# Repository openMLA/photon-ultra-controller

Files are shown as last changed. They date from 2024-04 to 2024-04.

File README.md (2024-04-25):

# Photon Ultra DLP controller

This repository contains PCB design files and code to control the UV projector found on the [Anycubic Photon Ultra](https://store.anycubic.com/products/photon-ultra). It also serves as a general example of how to send data to and control the [DCLP1438 DMD controller](https://www.ti.com/product/DLPC1438) through the parallel video interface.

The replacement board allows users to generate the signals required for the *DLP controller board* (designed by eViewTek) & DMD that comes with the photon ultra. It does not capture the full functionality of the Anycubic mainboard as it does not control the interface LCD, control the mechanics (stepper motor) or run any resin 3D printer slicer software. It **only** controls the DLP projector with an arbitrary 8-bit 1280x720 image. Exposure time can be set per image. It is also possible to play video on the projector, if that is something you have a use for. [Video has been tested up to 30Hz](https://github.com/openMLA/photon-ultra-controller/issues/1#issuecomment-2057936067), but should work up to 60Hz.

This project might be of interest to you if you **own a photon ultra** and are interested in either

1. Using the photon ultra for PCB fabrication (use the DLP to expose a photoresist)
2. Are looking to use a DMD for other applications but are not ready to build your own controller board.

If you are interested in learning more about the Photon Ultra, you can find more information on [this photon ultra teardown blog post](https://nemoandrea.github.io/blog/Anycubic_DLP_teardown/). More images are available on request.

> If you have a projector using the DLPC1438 that uses an SPI interface (rather than parallel video), then you can check out the [PCB design and implementation for the Elegoo-mars-4 DLP](https://github.com/openMLA/elegoo-mars-4-dlp-controller) projector.

### PCB

The PCB is designed around the standard 40-pin header present on the main Raspberry pi boards. Have a look at the required pins in the schematic to determine how to implement it for other boards.

The PCB readme also contains a breakdown of parts and cost in the BOM. The total PCB + raspberry pi zero 2 cost is around **65 euro** including tax. 

Keep in mind that you would also need to get your hands on the PCB and UV projector found in an Anycubic Photon Ultra. When it was still being sold in stores, that printer went for around **300 euros**. Second-hand options would be attractive, as the projector is unlikely to be significantly worn or covered in layers of sticky resin. Alternatively you can try contacting eViewTek and source the optical engine and driver board directly.

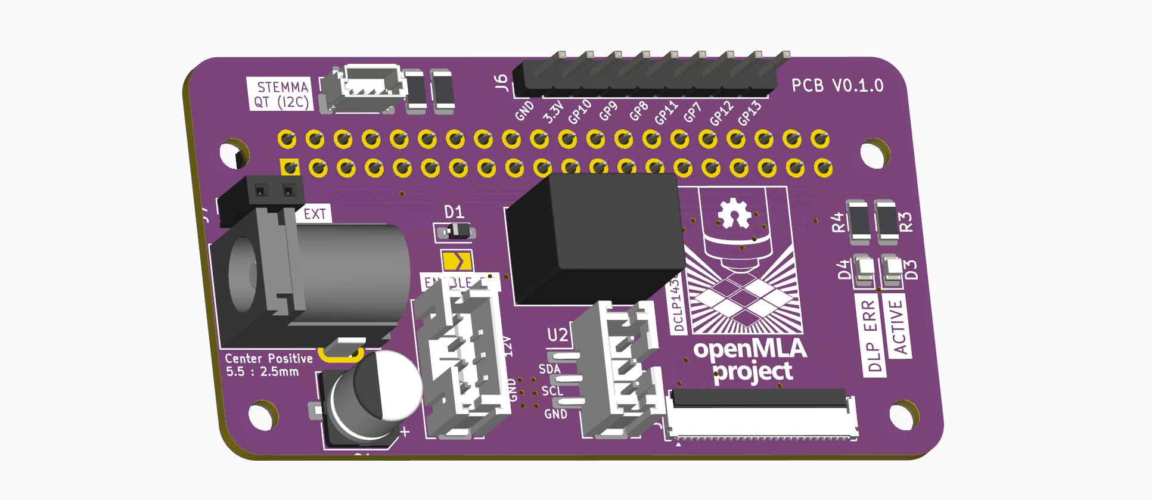
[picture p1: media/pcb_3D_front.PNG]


The PCB has been assembled and verified. Evaluated functionality:

* Powering a Raspberry Pi Zero 2
* Powering the eViewTek board
* software i2c communication (with DLPC1438)
* video display via the parallel interface on the DMD
* Status LED (not currently used in code, but they light up)

Not tested:

* The extra GPIO pins on top (including SPI)
* Stemma QT connection

### Context

This work was developed as part of the [openMLA project](https://github.com/openMLA), where the goal is to build an open hardware lithography system. Eventually an open hardware DLP controller board will be published as part of openMLA, but this represents an intermediate step. 

An earlier attempt at realising the right output format using a rp2040 was partially successful (image display was working), but memory limitations lead to the archiving of that project and the continuation with the current approach, The archived version [is still available](https://github.com/openMLA/photon-ultra-controller-rp2040) for those interested.

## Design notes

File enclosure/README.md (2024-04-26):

# 3D-printable enclosure 📦

To protect the electronics and keep the raspberry pi board in a good position relative to the eViewTek board, you can 3D-print the basic enclosure that is included in this directory. You will also need 7 10mm M2.5 bolts and screws.

Files were designed in FreeCAD.

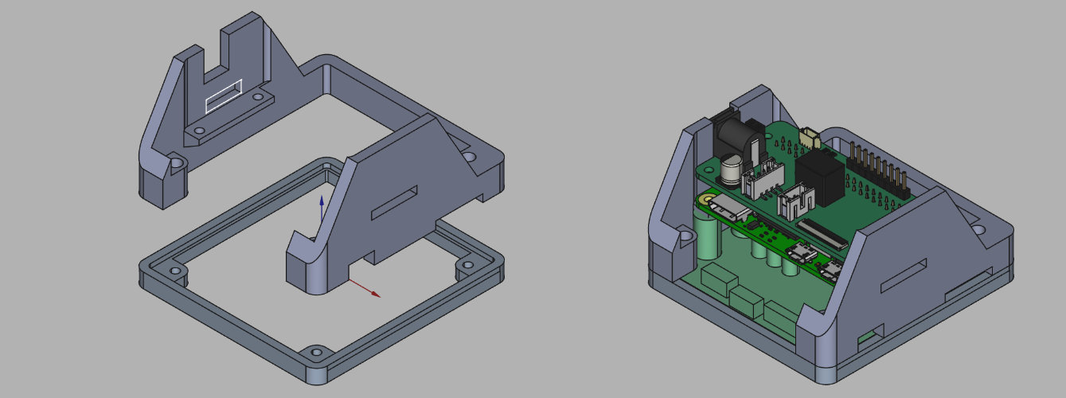
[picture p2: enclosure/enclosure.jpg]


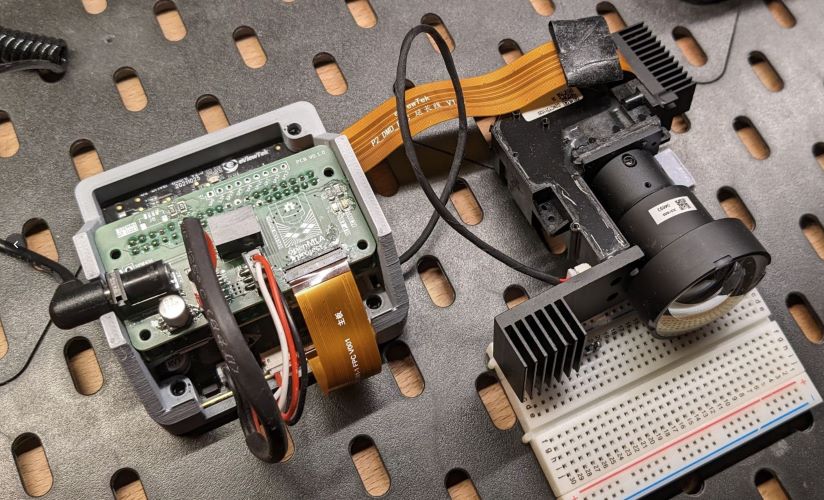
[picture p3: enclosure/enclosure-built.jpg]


### External 3D models

The Model of the raspberry Pi zero 2 was downloaded from [the geekworm wiki](https://wiki.geekworm.com/Raspberry_Pi_Zero_2_W) on 28th of february 2023.

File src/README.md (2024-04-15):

# Controlling the DLPC1438 with I2C and DPI

To control the eViewTek board (which in turn exposes the DCLP1438 parallel and i2c interface to use) we need to be able to output parallel RGB888 video in the right format and to send commands. 

Once you have set up the raspberry pi according to the configuration below, you can run the demo code in `main.py` and start playing around with the projector. 

If you want to play video (and timing is not super critical), you can install `mpv` and play video with `mpv <video.mp4>` (depending on orientation you may want to add `-vf=vflip`). Note that you will have to switch the projector into exposure mode (`Mode.EXTERNALPRINT`), otherwise you will not see anything. Any other means of playing video that modifies the framebuffer at `/dev/fb0` should also work.

### Configuring Raspberry pi OS Lite

>  Everything is tested on a Raspberry Pi Zero 2 running Raspbian GNU/Linux 12 (bookworm) (Lite).

To start, we need to make some changes to `/boot/config.txt`.

We need to disable the hardware I2C and SPI (for now at least). Make sure the `dtparams` for i2c, i2s, spi are all commented as below:

```shell
#Uncomment some or all of these to enable the optional hardware interfaces
#dtparam=i2c_arm=on
#dtparam=i2s=on
#dtparam=spi=on
```

Adding DPI: add the following lines: (note that in theory some of the back and front porches could be reduced according to datasheet; untested)

```
dtoverlay=vc4-kms-v3d
dtoverlay=vc4-kms-dpi-generic,hactive=1280,hfp=32,hsync=12,hbp=32
dtparam=vactive=720,vfp=6,vsync=5,vbp=6
dtparam=clock-frequency=32000000,rgb888,pixclk-invert
```

Add software I2C by adding the following lines:

```shell
# get software-defined i2c pin
dtoverlay=i2c-gpio,i2c_gpio_sda=17,i2c_gpio_scl=18,bus=8
```

If we were to leave the config.txt as above, we would lose all our GPIO, but we are not going to use the Green and Blue pixeldata pins anyway, so we would like to get those back for I2C, and other stuff. (i.e. switch them back out from their DPI `ALT` mode )

> [!NOTE]
> The method below works, but I would prefer to switch the pins out of ALT mode earlier on in the boot process. If you know how to do that, make an issue or pull request!

We can achieve this by putting the following in `/etc/rc.local`. Note that is must come before the `exit 0` line. 

```
raspi-gpio set 4-19 ip
```

Then we need to fix one final issue. If we start everything now, we notice that our framebuffer is running in RGB565 mode. Not sure why, but it is not what we want and doesn't match our DPI configuration. Luckily the fix is straightforward. We add the following to `/boot/cmdline.txt`:

```
`video=DPI-1:-32`
```
Note that the above that your DPI interface is called `DPI-1`. You can check this with `kmsprint`. It should list mode [`XR24`](https://www.linuxtv.org/downloads/v4l-dvb-apis-new/userspace-api/v4l/pixfmt-rgb.html). 

#### Checking results

Now (after rebooting) you should get something akin to the following if you run `fbset -fb /dev/fb0`

```shell
mode "1280x720"
    geometry 1280 720 1280 720 32
    timings 0 0 0 0 0 0 0
    accel true
    rgba 8/16,8/8,8/0,0/0
endmode
```

And something similar to the output below when you run `kmsprint`:

```shell
Connector 0 (32) HDMI-A-1 (disconnected)
  Encoder 0 (31) TMDS
Connector 1 (42) DPI-1 (connected)
  Encoder 1 (41) DPI
    Crtc 1 (71) 1280x720@32.02 32.000 1280/32/12/32/+ 720/6/5/6/+ 32 (32.02) P|D
      Plane 1 (61) fb-id: 294 (crtcs: 1) 0,0 1280x720 -> 0,0 1280x720 (XR24 AR24 AB24 XB24 RG16 BG16 AR15 XR15 RG24 BG24 YU16 YV16 YU24 YV24 YU12 YV12 NV12 NV21 NV16 NV61 RGB8 BGR8 XR12 AR12 XB12 AB12 BX12 BA12 RX12 RA12)
        FB 294 1280x720 XR24
```

You can also check the state of the GPIO pins with ``raspi-gpio get``. It should list something like: 

```
BANK0 (GPIO 0 to 27):
GPIO 0: level=0 alt=2 func=PCLK
GPIO 1: level=1 alt=2 func=DE
GPIO 2: level=0 alt=2 func=LCD_VSYNC
GPIO 3: level=0 alt=2 func=LCD_HSYNC
GPIO 4: level=1 func=INPUT
GPIO 5: level=1 func=INPUT
GPIO 6: level=0 func=INPUT
GPIO 7: level=1 func=INPUT
GPIO 8: level=1 func=INPUT
GPIO 9: level=0 func=INPUT
GPIO 10: level=0 func=INPUT
GPIO 11: level=0 func=INPUT
GPIO 12: level=0 func=INPUT
GPIO 13: level=0 func=INPUT
GPIO 14: level=0 func=INPUT
GPIO 15: level=1 func=INPUT
GPIO 16: level=0 func=INPUT
GPIO 17: level=1 func=INPUT
GPIO 18: level=1 func=INPUT
GPIO 19: level=0 func=INPUT
GPIO 20: level=0 alt=2 func=DPI_D16
GPIO 21: level=0 alt=2 func=DPI_D17
GPIO 22: level=0 alt=2 func=DPI_D18
GPIO 23: level=0 alt=2 func=DPI_D19
GPIO 24: level=0 alt=2 func=DPI_D20
GPIO 25: level=0 alt=2 func=DPI_D21
GPIO 26: level=0 alt=2 func=DPI_D22
GPIO 27: level=0 alt=2 func=DPI_D23
...
```

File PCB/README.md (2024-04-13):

### PCB design

The design is tested with a raspberry pi zero 2, but in principle any Raspberry pi will work. The hardware pins should all be shared, but some changes in raspberry Pi OS may break stuff for newer boards. 

See [the schematic](micromirror-board-controller.pdf) for more info.



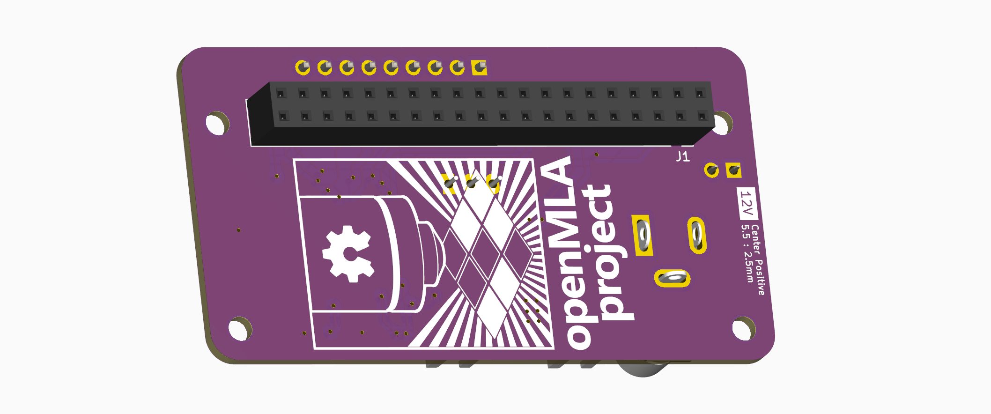
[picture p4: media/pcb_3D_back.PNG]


### Assembly

Most components are SMD, and the mouser links can be found in the basic [BOM](BOM.csv). In addition to the components of the BOM, you will also need some small wires to connect the USB data lines.

That 51-pin connector is a real pain to solder. For me going with a lower melting point solder and proper board heating made it manageable, but it's not the most enjoyable experience.

### BOM

The prices below include Dutch VAT tax (21%). 

| Description | Supplier | Supplier Part Number | Amount | Total Cost | Comment |
| --- | --- | --- | --- | --- | --- |
| PCB manufacturing | Aisler | | 3 | 16.16 | MOC 3pcs |
| Raspberry Pi Zero 2 | Mouser | 358-SC0510 | 1 | 16.9 | |
| Micro SD Card (32GB) | Kiwi Electronics | TS32GUSDU1 | 1 | 10 | Whatever kind you want would work |
| Raspberry pi header | Kiwi Electronics | KW-2639 | 1 | 2 | or any basic, cheaper header |
| Raspberry pi header female | Kiwi Electronics | KW-1650 | 1 | 1.5 | |
| JST SH 4-pin | Mouser | 474-PRT-16766 | 1 | 0.67 | Optional, allows i2c through  stemmaQT/QWIIC |
| Cui DC-DC converter | Mouser | 490-P78E05-1000 | 1 | 3.45 | |
| Barreljack | Mouser | 490-PJ-002B | 1 | 0.79 | |
| Schottky Diode | Mouser | 771-PMEG1020EJ-T/R | 1 | 0.29 | |
| 100uF capacitor | Mouser | 667-EEE-FN1E101UP | 1 | 0.57 | |
| 4.7k Ohm pullup resistor | Mouser | 667-ERA-8AEB472V | 2 | 0.87 | |
| 330 Ohm resistor | Mouser | 667-ERA-8AEB331V | 2 | 0.75 | |
| Green LED | Mouser | 710-150080VS75000 | 1 | 0.22 | |
| Red LED | Mouser | 710-150080RS75000 | 1 | 0.22 | |
| 51-pin FPC connector | Mouser | 798-FH35C51S03SHW50  | 1 | 3.52 | not fun to solder |
| 3 -pin JST PH connector (10pack) | Mouser | 485-4389 | 1 | 3.95 | Probably best to find the single-unit part |
| 4-pin JST PH connector (10pack)  | Mouser | 485-4390 | 1 | 3.95 | Probably best to find the single-unit part |
| | | | | | |
| Total | | | | 65.77 | |

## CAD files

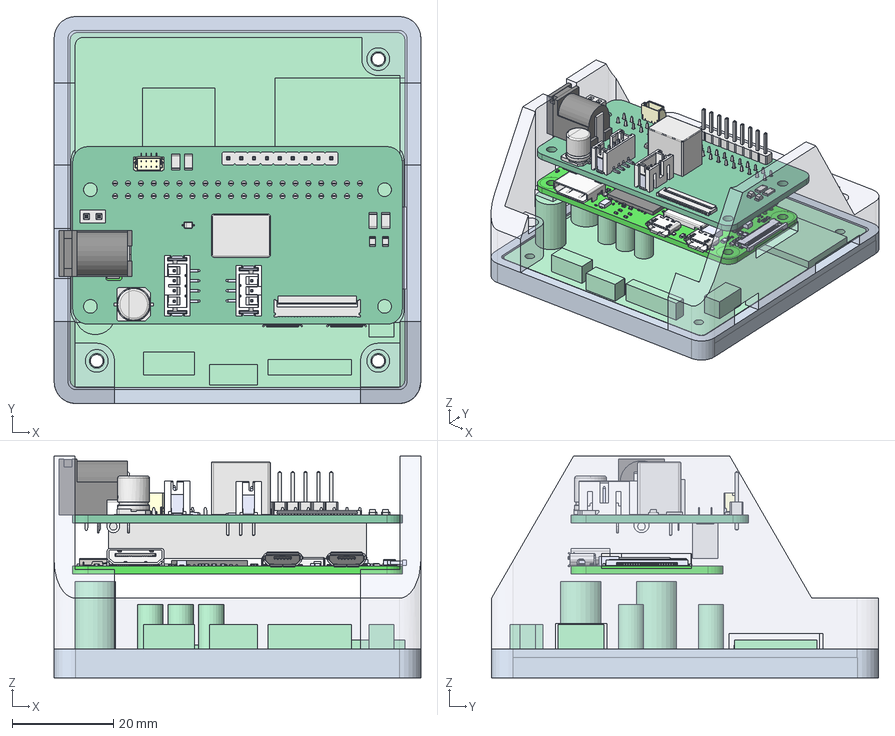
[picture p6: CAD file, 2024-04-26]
enclosure/enclosure.FCStd
72.3 x 76.3 x 43.7 mm
PCB, Raspberry Pi Zero 2 W
RP3A0-AU 2105 201221C, Raspberry Pi Zero 2 W
MicroUSB Port, Raspberry Pi Zero 2 W
MicroUSB Port, Raspberry Pi Zero 2 W001
MicroUSB Port, Raspberry Pi Zero 2 W002
MicroUSB Port, Raspberry Pi Zero 2 W003
MicroUSB Port, Raspberry Pi Zero 2 W004
MicroUSB Port, Raspberry Pi Zero 2 W005
MicroUSB Port, Raspberry Pi Zero 2 W006
SD Card Slot, Raspberry Pi Zero 2 W
SD Card Slot, Raspberry Pi Zero 2 W001
SD Card Slot, Raspberry Pi Zero 2 W002
SD Card Slot, Raspberry Pi Zero 2 W003
SD Card Slot, Raspberry Pi Zero 2 W004
SD Card Slot, Raspberry Pi Zero 2 W005
SD Card Slot, Raspberry Pi Zero 2 W006
SD Card Slot, Raspberry Pi Zero 2 W007
SD Card Slot, Raspberry Pi Zero 2 W008
SD Card Slot, Raspberry Pi Zero 2 W009
Wireless Module Cover, Raspberry Pi Zero 2 W
Crystal Resonator, Raspberry Pi Zero 2 W
LED, Raspberry Pi Zero 2 W
Diode, Schottky, Raspberry Pi Zero 2 W
54548-2271, 22 Pin FPC Connector, Raspberry Pi Zero 2 W
Mini HDMI Receptacle Port, Raspberry Pi Zero 2 W
PAM2306AYPKE, Switching Voltage Regulators Dual PWM Step-Down 40uA 1A 1.5MHz, Raspberry Pi Zero 2 W
RT9081A-1BGQZA, Fixed LDO Voltage Regulator, 0.8V-5.5Vin, 140mV drop, 1.25Vout, 0.5Aout, Raspberry Pi Zero 2 W_default
RT8088AWSC, IC Reg Buck Prog 3A Sync 15WLCSP, Raspberry Pi Zero 2 W_default
SMD Inductor, Configurable, Raspberry Pi Zero 2 W_L1
SMD Inductor, Configurable, Raspberry Pi Zero 2 W_L2
SMD Capacitor, Configurable, Raspberry Pi Zero 2 W_C1
SMD Capacitor, Configurable, Raspberry Pi Zero 2 W_C002
SMD Capacitor, Configurable, Raspberry Pi Zero 2 W_C003
MicroUSB Port, Raspberry Pi Zero 2 W008
MicroUSB Port, Raspberry Pi Zero 2 W009
MicroUSB Port, Raspberry Pi Zero 2 W010
MicroUSB Port, Raspberry Pi Zero 2 W011
MicroUSB Port, Raspberry Pi Zero 2 W012
MicroUSB Port, Raspberry Pi Zero 2 W013
MicroUSB Port, Raspberry Pi Zero 2 W014
SMD Capacitor, Configurable, Raspberry Pi Zero 2 W_C3
SMD Capacitor, Configurable, Raspberry Pi Zero 2 W_C005
SMD Capacitor, Configurable, Raspberry Pi Zero 2 W_C006
SMD Capacitor, Configurable, Raspberry Pi Zero 2 W_C008
SMD Capacitor, Configurable, Raspberry Pi Zero 2 W_C009
SMD Capacitor, Configurable, Raspberry Pi Zero 2 W_C010
SMD Capacitor, Configurable, Raspberry Pi Zero 2 W_C012
SMD Capacitor, Configurable, Raspberry Pi Zero 2 W_C013
SMD Capacitor, Configurable, Raspberry Pi Zero 2 W_C014
SMD Capacitor, Configurable, Raspberry Pi Zero 2 W_C016
SMD Capacitor, Configurable, Raspberry Pi Zero 2 W_C017
SMD Capacitor, Configurable, Raspberry Pi Zero 2 W_C018
SMD Capacitor, Configurable, Raspberry Pi Zero 2 W_C020
SMD Capacitor, Configurable, Raspberry Pi Zero 2 W_C021
SMD Capacitor, Configurable, Raspberry Pi Zero 2 W_C022
SMD Capacitor, Configurable, Raspberry Pi Zero 2 W_C024
SMD Capacitor, Configurable, Raspberry Pi Zero 2 W_C025
SMD Capacitor, Configurable, Raspberry Pi Zero 2 W_C026
SMD Capacitor, Configurable, Raspberry Pi Zero 2 W_C028
SMD Capacitor, Configurable, Raspberry Pi Zero 2 W_C029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

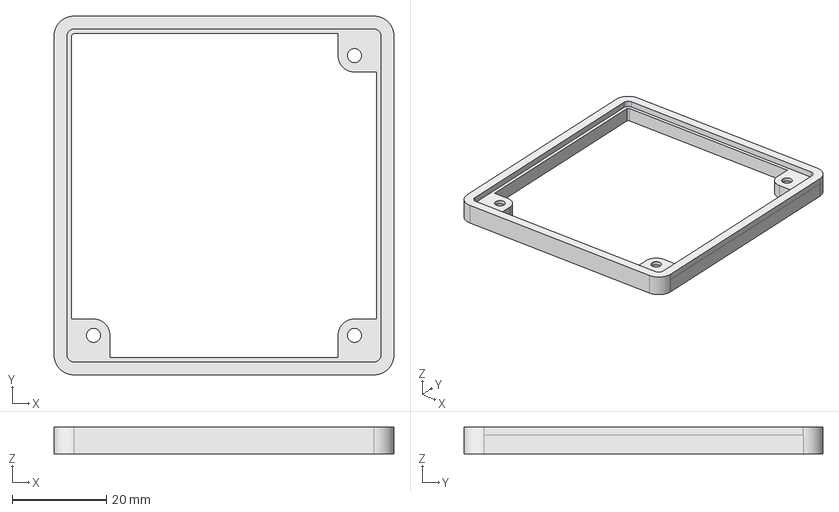
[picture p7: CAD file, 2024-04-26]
enclosure/step/enclosure-bottom.step
72.3 x 76.3 x 5.70 mm

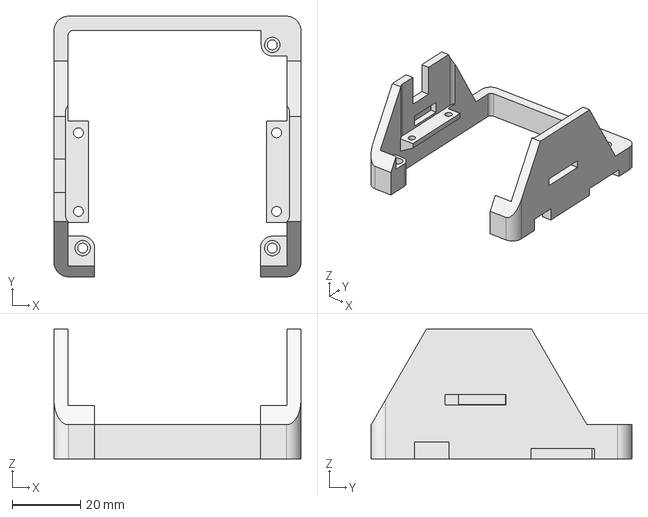
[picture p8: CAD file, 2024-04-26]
enclosure/step/enclosure-top.step
72.3 x 76.3 x 38.0 mm

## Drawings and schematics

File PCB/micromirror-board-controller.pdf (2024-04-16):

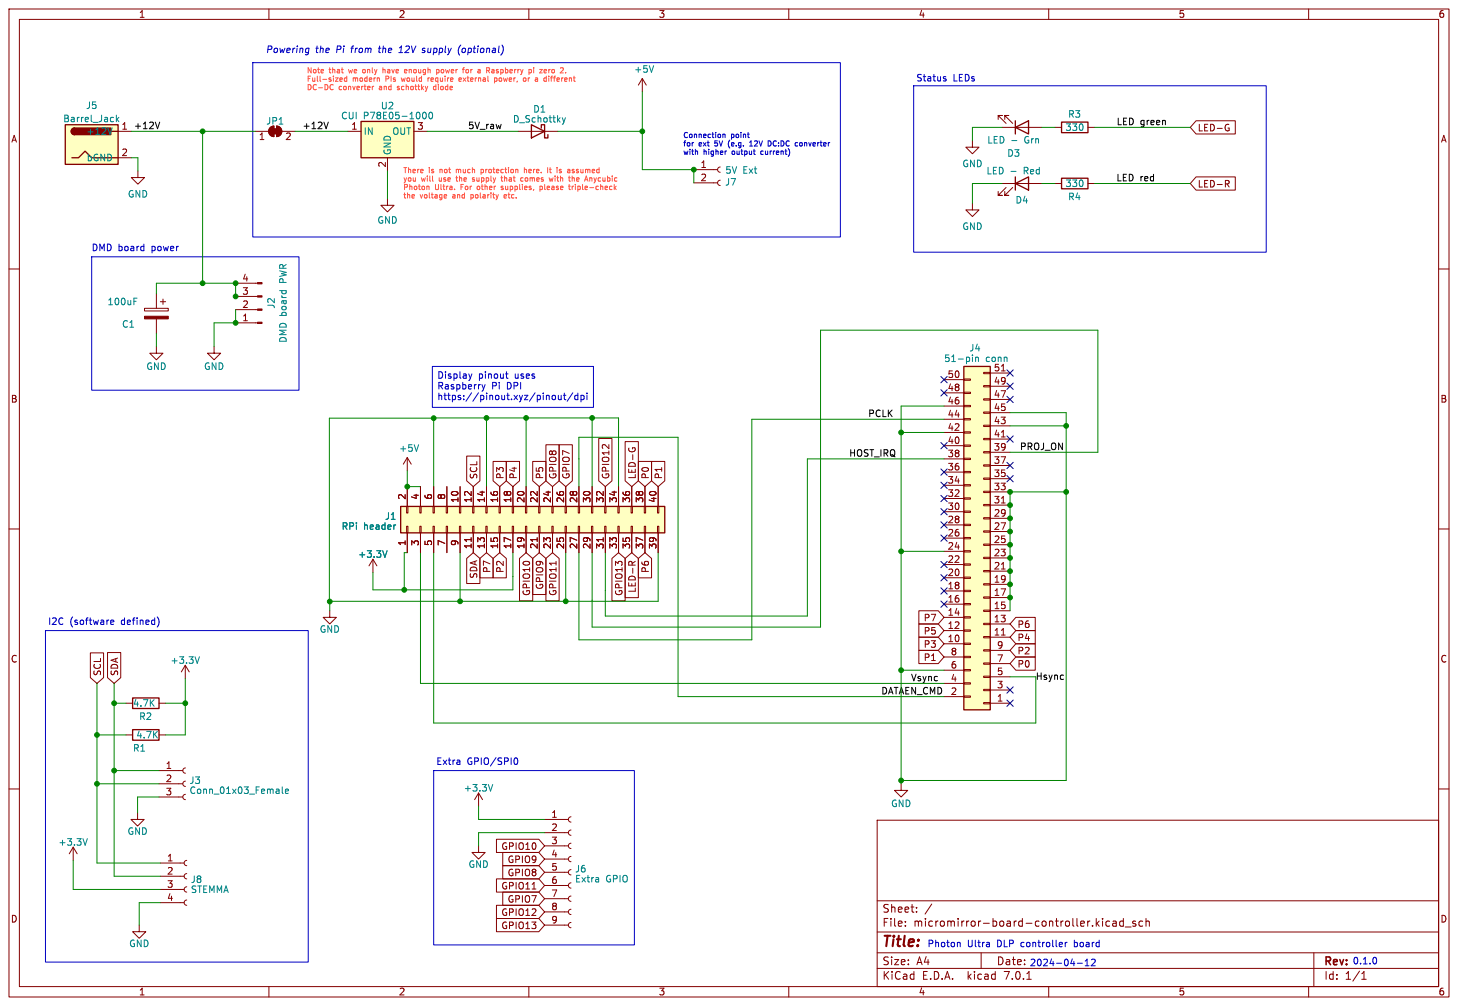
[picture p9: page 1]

for ext 5V (e.g. 12V DC:DC converter with higher output current)

Id: 1/1 Title: File: micromirror-board-controller.kicad_sch Sheet: /

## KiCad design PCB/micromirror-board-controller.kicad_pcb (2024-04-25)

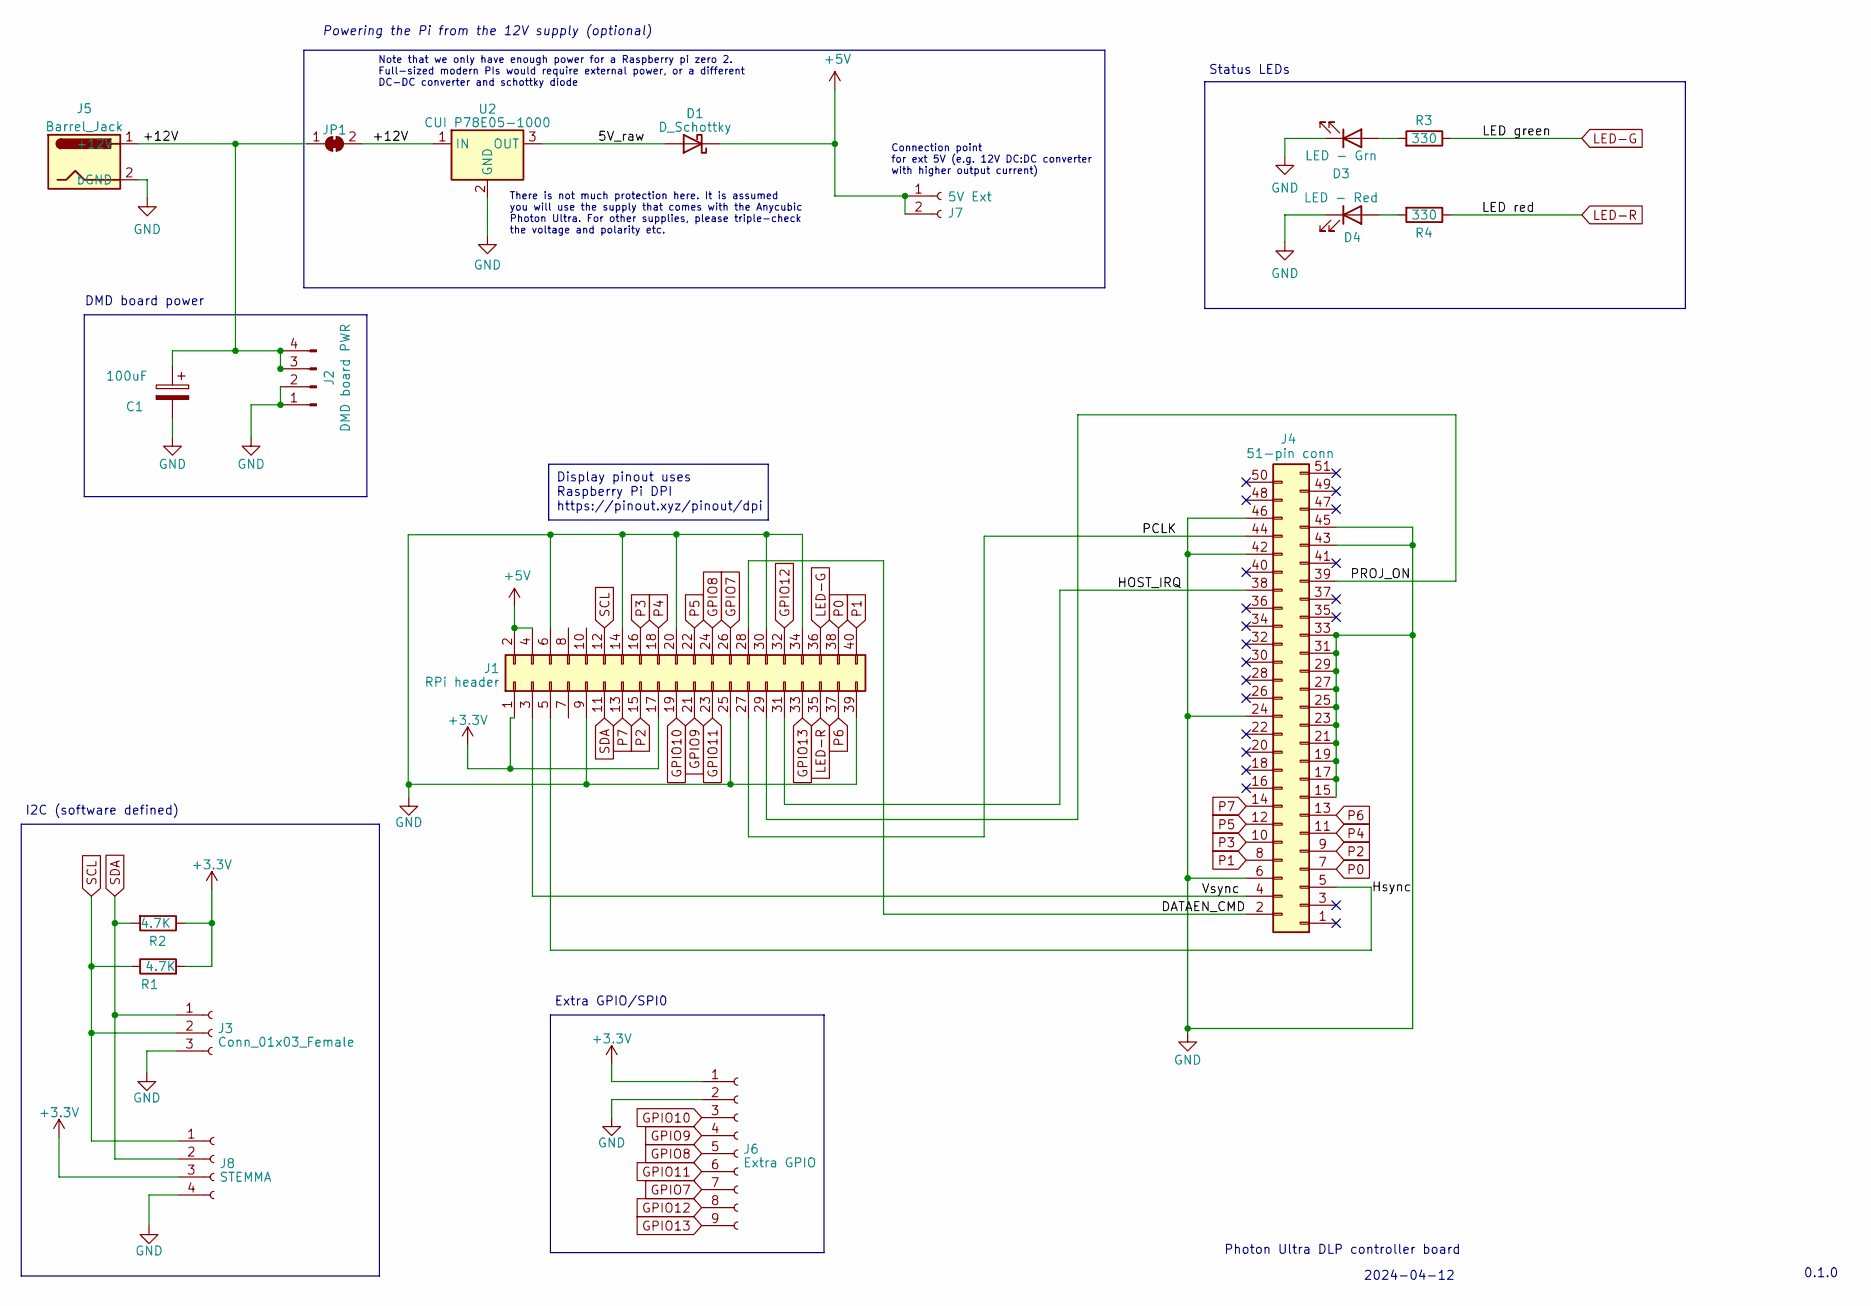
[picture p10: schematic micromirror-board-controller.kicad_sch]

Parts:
C1: 100uF; CP_Elec_6.3x7.7
D1: D_Schottky; D_SOD-323_HandSoldering; Mouser 771-PMEG1020EJ-T/R
D3: LED - Grn; LED_0805_2012Metric; Mouser 710-150080VS75000
D4: LED - Red; LED_0805_2012Metric; Mouser 710-150080RS75000
J1: RPi header; PinSocket_2x20_P2.54mm_Vertical
J2: DMD board PWR; JST_PH_B4B-PH-SM4-TB_1x04-1MP_P2.00mm_Vertical; Mouser 485-4390
J3: Conn_01x03_Female; JST_PH_B3B-PH-SM4-TB_1x03-1MP_P2.00mm_Vertical; Mouser 485-4389
J4: 51-pin conn; Molex_502250-5191_2Rows-51Pins-1MP_P0.60mm_Horizontal; Mouser-id 798-FH35C51S03SHW50
J5: Barrel_Jack; BarrelJack_GCT_DCJ200-10-A_Horizontal
J6: Extra GPIO; PinHeader_1x09_P2.54mm_Vertical
J7: 5V Ext; PinSocket_1x02_P2.54mm_Vertical
J8: STEMMA; JST_SH_BM04B-SRSS-TB_1x04-1MP_P1.00mm_Vertical; Mouser 474-PRT-16766
JP1: SolderJumper_2_Bridged; SolderJumper-2_P1.3mm_Open_TrianglePad1.0x1.5mm
R1: 4.7K; R_1206_3216Metric
R2: 4.7K; R_1206_3216Metric; Mouser 667-ERA-8AEB472V
R3, R4: 330; R_1206_3216Metric
U2: CUI P78E05-1000; Converter_DCDC_RECOM_R-78E-0.5_THT; Mouser 490-P78E05-1000

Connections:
+3.3V: J1.1, J1.17, J6.1, J8.3, R1.2, R2.1
+5V: D1.1 (K), J1.2, J1.4, J7.1, J7.2
/5V_raw: D1.2 (A), U2.3 (OUT)
/+12V: C1.1, J2.3, J2.4, J5.1 (+12V), JP1.1 (A), JP1.2 (B), U2.1 (IN)
/DATAEN_CMD: J1.28, J4.2 (DATAEN)
/HOST_IRQ: J1.31, J4.38 (HOST_IRQ)
/Hsync: J1.5, J4.5 (Hsync)
/PCLK: J1.27, J4.44 (PCLK)
/PROJ_ON: J1.29, J4.39 (GPIO_9)
/Vsync: J1.3, J4.4 (Vsync)
GND: C1.2, D3.1 (K), D4.1 (K), J1.6, J1.9, J1.14, J1.20, J1.25, J1.30, J1.34, J1.39, J2.1, J2.2, J3.3 (SDA), J4.6 (GND), J4.15 (GND), J4.17, J4.19, J4.21, J4.23, J4.24, J4.25, J4.27, J4.29, J4.31, J4.33, J4.42 (GND), J4.43 (GND), J4.45 (GND), J4.46 (GND), J5.2 (bGND), J6.2, J8.4, U2.2 (GND)
GPIO7: J1.26, J6.7
GPIO8: J1.24, J6.5
GPIO9: J1.21, J6.4
GPIO10: J1.19, J6.3
GPIO11: J1.23, J6.6
GPIO12: J1.32, J6.8
GPIO13: J1.33, J6.9
LED-G: J1.36, R3.1
LED-R: J1.35, R4.1
unnamed: D3.2 (A), R3.2
unnamed: D4.2 (A), R4.2
P0: J1.38, J4.7 (P1)
P1: J1.40, J4.8 (P0)
P2: J1.15, J4.9 (P3)
P3: J1.16, J4.10 (P2)
P4: J1.18, J4.11 (P5)
P5: J1.22, J4.12 (P4)
P6: J1.37, J4.13 (P7)
P7: J1.13, J4.14 (P6)
SCL: J1.12, J3.2 (SCL), J8.1, R1.1
SDA: J1.11, J3.1 (dGND), J8.2, R2.2

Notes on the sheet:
Display pinout uses Raspberry Pi DPI https://pinout.xyz/pinout/dpi
Extra GPIO/SPI0
There is not much protection here. It is assumed you will use the supply that comes with the Anycubic Photon Ultra. For other supplies, please triple-check the voltage and polarity etc.
Connection point for ext 5V (e.g. 12V DC:DC converter with higher output current)
Powering the Pi from the 12V supply (optional)
Status LEDs
Note that we only have enough power for a Raspberry pi zero 2. Full-sized modern PIs would require external power, or a different DC-DC converter and schottky diode
DMD board power
I2C (software defined)
Photon Ultra DLP controller board
2024-04-12
0.1.0

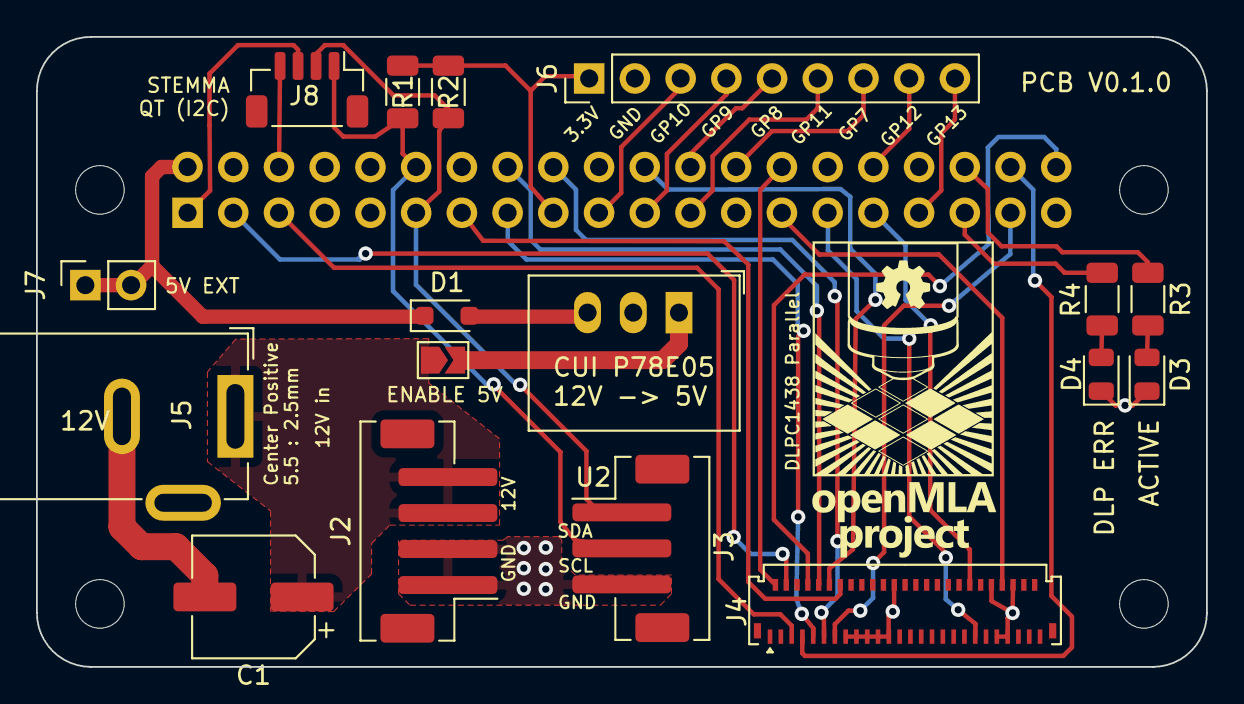
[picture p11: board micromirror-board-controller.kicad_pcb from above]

Board: 2 copper layers, 65.0 x 35.0 mm, 22 parts (1 on the bottom side), 32 nets.

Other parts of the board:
MH1, MH2, MH3, MH4: MountingHole_2.7mm_M2.5

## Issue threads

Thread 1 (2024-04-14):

Maximum Framerate

beniroquai, 2024-04-14:
Hey @NemoAndrea, great stuff - as always! :)
May I ask you what would be the maximum framerate you could achieve with this device? I remember you mentioned 2fps for some DMD+Raspi combination, but this may be different since you use a different controlling interface?
Thanks!:)

NemoAndrea, 2024-04-14:
With the parallel interface and leaving the DMD to keep exposing (no dark frames), it seems to be handling video playback at 30Hz okay, but I need to do more thorough testing to see if it can actually display all 30 frames. But it looks like video alright.

In theory cranking it to 60Hz should be possible; will give it a shot when I find some time. (need to find something to record images with reliably etc)

beniroquai, 2024-04-15:
That's awesome! I want one ;D
The DLP modules from anycubic are available as a spare part or do you need to go through the full teardown everytime you need one? ;-)

NemoAndrea, 2024-04-15:
eViewTek will (when I asked in january 2024) sell you the optical engine and diver board separately. I was able to get a quote, which was pretty reasonable. I don't know how much stock they have and if they are keeping it in production.

NemoAndrea, 2024-04-15:
Now in 8-bit :) This should still be ~30Hz

https://github.com/openMLA/photon-ultra-controller/assets/8851596/1073c735-3f78-4d0c-9457-03acd0ee8ca6

beniroquai, 2024-04-16:
Wow! That is super cool! It's a natural idea to think of using this DMD as the pattern generator for our SIM systems. I'm looking for old Elegoos on Ebay. Maybe I find one that is not that expensive. Impressive! Thanks for sharing. 30 fps is already pretty awesome. One could use the raspi as the trigger device, too, right?

CC: @ranranking

NemoAndrea, 2024-04-16:
Yep, the expose can be enabled over i2c. There is then the option to (1) expose for a certain amount of frames, controlled/intrepreted by the DLPC1438, to (2) to expose until the "STOP EXPOSURE" i2c command is sent.

So you could leave it in mode (2) and use the framebuffer to switch between expose/stop light/change pattern/light on/expose/ stop light/change pattern/  or (1) and i2c-start->expose->i2c-stop->change pattern->i2c-start->expose. Depends a bit on how problematic the "changing DMD mirror positions" is as it transitions between frames I guess.

beniroquai, 2024-04-16:
Amazing! Thanks a lot for all the information! I found one on ebay. Potentially broken. Awesome! ^^

Closed 2024-04-15.

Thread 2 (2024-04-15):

grayscale pins swapped

NemoAndrea, 2024-04-15:
Noticed that the grayscale pins are swapped in board revision 0.1.0. Need to correct in PCB design. Happy I caught that before ordering and assembling.

(pins 0<->1, pins 2<->3, etc).

Closed 2024-04-16.

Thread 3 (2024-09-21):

Would this be directly compatible with a Pi 3b or a Pi4?

X3msnake, 2024-09-21:
Managed to aquire one Ultra as is returns on official anycubic ebay.

I wanted to use @sn4k3 [Klipper-MSLA](https://github.com/sn4k3/klipper-msla ) branch to controll a custom printer with zoom and focus capacity on the DLP side.

Would the current shield work directly on a Pi3B, Pi4 or would i need to make changes to the schematic?

Btw do you have a paypal tip button anywhere?
Thanks in advance

sn4k3, 2024-09-21:
I have an additional question, I saw you using software I2C, any special reason to go software instead of hardware I2C?

NemoAndrea, 2024-10-20:
I think it should work on those Pis, but the thing to check would be if there are any special changes with the respect to the Display Parallel Interface (DPI). Other than that i think the hardware should be fine.

Please do report back if it gives you trouble; we can try to see what must be changed software wise or hardware.

NemoAndrea, 2024-10-20:
> I have an additional question, I saw you using software I2C, any special reason to go software instead of hardware I2C?

The DPI occupies the hardware i2c pins and they cannot be remapped unfortunately. So software it is 😃

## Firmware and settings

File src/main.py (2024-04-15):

import RPi.GPIO as GPIO
import time
import smbus  # I2C
from PIL import Image

from UV_projector.controller import DLPC1438, Mode

GPIO.setmode(GPIO.BCM)

HOST_IRQ = 6  # GPIO pin for HOST_IRQ
PROJ_ON = 5  # GPIO pin for PROJ_ON

i2c = smbus.SMBus(8)  # we configured our software i2c to be on bus 8

### Controlling DMD ################################################################################

# Initialise the DLPC1438
DMD = DLPC1438(i2c, PROJ_ON, HOST_IRQ)
# Configure it (NOTE: Mode.STANDBY can clear these settings, so call it again after standby)
DMD.configure_external_print(LED_PWM=1023)

# switch to right mode
DMD.switch_mode(Mode.EXTERNALPRINT)

DMD.expose_pattern(-1)  # expose for infinite duration (until we stop it)

### Writing data to framebuffer ####################################################################

import numpy as np

# Map the screen as Numpy array
# the framebuffer is XR24 (BGRX) - https://www.linuxtv.org/downloads/v4l-dvb-apis-new/userspace-api/v4l/pixfmt-rgb.html
# (you can check this with `kmsprint`)

# in XR24, byte3 corresponds to the RED channel and since we have our raspberry pi DPI
# pins wired to the red channel, we need to write to those bytes with our code.

h, w, c = 720, 1280, 4
fb = np.memmap('/dev/fb0', dtype='uint8',mode='w+', shape=(h, w, c)) 
 
# fb.shape = (720,1280,4)
# we first zero the framebuffer (otherwise you can get an image of the terminal :P)
fb[:,:, 0] = 0 
fb[:,:, 1] = 0 
fb[:,:, 2] = 0 

print(">> Example: primaries (RGB, only blue matters)") ############################################

# blue  # should be dark
fb[:,:, 0] = 255 
fb[:,:, 1] = 0 
fb[:,:, 2] = 0 

input("Press Enter to continue...")
# green  # should be dark
fb[:,:, 0] = 0 
fb[:,:, 1] = 255 
fb[:,:, 2] = 0 
input("Press Enter to continue...")
#fb[:] = red   # THIS SHOULD result in full brightness
fb[:,:, 0] = 0 
fb[:,:, 1] = 0 
fb[:,:, 2] = 255 
input("Press Enter to continue...")

print(">> Example: ramping grayscale") #############################################################

for i in range(255):
    print(f'Intensity val {i}')
    fb[:,:, 2] = i 
    time.sleep(0.1) 
input("Press Enter to continue...")

print(">> Example: displaying a png image") ########################################################

print("-- Converting image to bytes --")
print(fb.shape)
im_frame = Image.open("../media/openMLA_logo_1280x720.png")
pixeldata = np.array(im_frame)

fb[:,:,2] = pixeldata
input("Press Enter to continue...")

print(">> Example: repeating grayscale gradient (1px per step)") ###################################

row = np.arange(1280) % 255
grad_array = np.tile(row, (720, 1))
fb[:,:,2] = grad_array
input("Press Enter to continue...")

print(">> Example: A cube. Yeah, thrilling.") ######################################################

cube = np.zeros((720,1280))
cube[300:400, 300:400] = 100
fb[:,:,2] = cube
input("Press Enter to continue...")

# turn light off
DMD.stop_exposure()  

time.sleep(0.3)
DMD.switch_mode(Mode.STANDBY)  # leave system in standby

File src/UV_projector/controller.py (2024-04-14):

import warnings
import RPi.GPIO as GPIO
import time
import enum
import math
import numpy as np

class Mode(enum.IntEnum):
    STANDBY = 0xFF,
    EXTERNALPRINT = 0x06,
    TESTPATTERN = 0x01
    
class DLPC1438:
    """
    Representation of the DLPC1438 DMD controller. Communication between the user board (raspberry
    pi) and the DLPC1438 are handled will this class. It is assumed the image data is
    being transmitted over the parallel video interface of the DCLP1438, and that this
    image data is being stored in frame buffer 0 (/dev/fb0). 
    """

    addr = 0x1B  # i2c address

    def __init__(self, i2c_bus, PROJ_ON_PIN, HOST_IRQ_pin):
        """
        Checks if the DCLP1438 is running and ready for i2c communication, and if not, will 
        start the DLPC1438 with the PROJ_ON gpio signal.
        """
        print("Intialising the DLPC1438...")

        self.PROJ_ON = PROJ_ON_PIN
        self.HOST_IRQ = HOST_IRQ_pin

        # Configure the pins
        GPIO.setup(self.PROJ_ON, GPIO.OUT)  
        GPIO.setup(self.HOST_IRQ, GPIO.IN)  

        self.i2c = i2c_bus

        # Reset the DCLP1438
        GPIO.output(self.PROJ_ON, GPIO.LOW)    
        time.sleep(1)
            
        # send the PROJ_ON signal and wait for the HOST_IRQ signal to go high, signalling the DLPC1438
        # is ready to go
        GPIO.output(self.PROJ_ON, GPIO.HIGH)
        ref_time = time.time()
        while not GPIO.input(self.HOST_IRQ):
            time.sleep(0.001)

        print(f"DLPC1438 is signalling it is ready for use, {time.time()-ref_time} seconds after PROJ_ON went high.")

        # wait until we can see the DLPC1438 on i2c bus
        while True:
            time.sleep(0.05)
            try:
                # Try reading from DCLP1438. Will give OSError if not found (yet)
                self.i2c.read_byte(self.addr)
                print(f"DCLP1438 is ready for i2c communication")

                time.sleep(0.3)  # we need some extra wait time after this TODO: figure out why

                break  # break out of while loop and continue
            except OSError:
                #print("waiting for i2c...")
                # DLPC1438 i2c not ready yet. Ignore and try again
                pass

        return
        
    def __i2c_read(self, register, length):
        """Read I2C information from DCLP1438 at given register, expecting a certain number of bytes
        of data.
        
        This function exists primarily to keep a code more readable."""
        return self.i2c.read_i2c_block_data(self.addr,register,length)
    
    def __i2c_write(self, register, data):
        """Write I2C information from DCLP1438 at given register, sending a list of bytes specified
        in 'data'.
        
        This function exists primarily to keep a code more readable."""
        return self.i2c.write_i2c_block_data(self.addr,register,data)

    def switch_mode(self, new_mode):
        """
        Switch between DLPC1438 operational modes.

        Note that the input of the function must be an Enum of the Mode class.
        """
        # check that the new mode is actually a valid enum entry 
        if isinstance(new_mode, Mode):  
            print(f"> Switching DLPC1438 mode to {new_mode.name}\t (currently in {self.__i2c_read(0x06,1)[0]})")

            self.__i2c_write(0x05, [new_mode])  # send the new mode setting

            time.sleep(0.4)  # need some time to switch between modes

            # check that the mode switch was successful
            if new_mode != Mode.STANDBY: 
                queried_mode = self.__i2c_read(0x06,1)[0]
                assert queried_mode == new_mode.value, f"Was unable to switch the DLPC 1438 to MODE:{new_mode}"
            else:  # STANDBY sometimes gives a different status code. If so you can handle it here.
                # TODO: figure out why this gives different code sometimes
                queried_mode = self.__i2c_read(0x06,1)[0]
                print(f"Standby status: {queried_mode}")
                assert queried_mode == new_mode.value, f"Was unable to switch the DLPC 1438 to MODE:{new_mode}"

            # if we switched to EXTERNAL_PRINT mode, we will want to wait for 
            # SYS_READY to go high before doing anything else. eViewTek board does not
            # expose pin over the FPC, so we we will just wait for 1s.
            if queried_mode == Mode.EXTERNALPRINT:
                time.sleep(1)

        else:
            raise Exception("Invalid DLPC1438 mode provided. Use the Enum 'Mode', rather than the hex value.")
    
    def configure_external_print(self, LED_PWM): 
        """
        Apply various settings applicable to the EXTERNAL_PRINT mode of the DLPC1438.

        This function will configure multiple registers. Note that switching to STANDBY mode will
        likely reset some of these values, so it is suggested to call this before switching
        to EXTERNAL_PRINT mode.
        """

        print(f"\nConfiguring the DLPC1438 for external print mode with LED PWM at {LED_PWM/1023*100}%")

        assert isinstance(LED_PWM, int), "LED_PWM must be a 10-bit integer"
        assert 0 <= LED_PWM < 1024, "LED_PWM must be 10-bit (i.e. in range [0, 1023])"

        # write external print confugration (0xA8)
        # we choose a linear transfer function (byte 1) and select led 3 (byte 2)
        self.__i2c_write(0xA8, [0x00, 0x04])  # set gamma and led
        print(f"External print settings: {self.__i2c_read(0xA9,2)}")

        # Write LED PWM current (0x54)
        # Set PWM value for LED 3 (default anycubic is (0xB4, 0x00))
        print(LED_PWM.to_bytes(2, byteorder = 'big'))
        PWM_data = [0x00, 0x00, 0x00, 0x00] + list(LED_PWM.to_bytes(2, byteorder = 'little'))
        self.__i2c_write(0x54, PWM_data)  
        print(f"LED settings: {[hex(val) for val in self.__i2c_read(0x55,6)]}") 

        # set image orientation
        self.__i2c_write(0x14, [0x00])
        

    def expose_pattern(self, exposed_frames, dark_frames=5):
        """
        Start exposure of the data on parallel video interface with a specified number of exposed frames.

        The exposure time is set in number of frames. I assume this is in the framerate
        set by the parallel interface. 

        Dark frames are there to minimise any switching artifacts. I havent tested well enough
        if it makes a difference. It looks smooth enough when playing back video, so it
        seems safe to run with dark_frames=0
        """
        # Ideally we would check SYS_READY signal here
        assert isinstance(dark_frames, int), "dark_frames must be a 16-bit integer"
        assert 0 <= dark_frames < 65536, "dark_frames must be 16-bit (i.e. in range [0, 65535])"

        if exposed_frames > 0:
            assert isinstance(exposed_frames, int), "exposed_frames must be a 16-bit integer"
            assert 0 <= exposed_frames < 65536, "exposed_frames must be 16-bit (i.e. in range [0, 65535])"
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

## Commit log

2024-04-12 Add intial PCB files
    Early draft of PCB
    [micromirror-board-controller.kicad_pcb, micromirror-board-controller.kicad_sch]
2024-04-13 functional parallel routing
    [micromirror-board-controller.kicad_pcb, micromirror-board-controller.kicad_sch]
2024-04-13 Completed routing and schematic
    Did all the routing for the board. Schematic also close to final.
    [micromirror-board-controller.kicad_pcb, micromirror-board-controller.kicad_sch]
2024-04-13 Added board silkscreen
    Added proper pin labels and project graphics
    [micromirror-board-controller.kicad_pcb]
2024-04-13 Complete 3D model for PCB
    Added the 3D footprints for PCB. 3D view now displays everyhing as expected.
    [micromirror-board-controller.kicad_pcb]
2024-04-13 fix silkscreen error
    [micromirror-board-controller.kicad_pcb]
2024-04-13 Add BOM
    Add the bill of materials. Fixed some of the part number formatting in the schematic.
    [micromirror-board-controller.kicad_sch]
2024-04-14 Remove old spi code block
    Fix issue with python code that still contained references to spi approach of elegoo mars 4 DLP code.
    [controller.py]
2024-04-15 Working code for 8-bit grayscale
    Add working 8-bit grayscale code. Noticed that some of the pins are swapped; will fix in PCB design
    [main.py]
2024-04-15 Add raspberry pi configuration instructions
    Added step-by-step instructions on how to configure raspberry pi to produce correct DPI output.
2024-04-16 Fix incorrect pinout for pixeldata
    Corrected the incorrect pinout of the pixeldata section of the FPC connector. Even and odd pins had to be switched (P0 <-> P1) etc. Fixes https://github.com/openMLA/photon-ultra-controller/issues/2.
    [micromirror-board-controller.kicad_pcb, micromirror-board-controller.kicad_sch]
2024-04-17 Move barrel jack slightly for enclosure purposes
    Moved the DC barrel jack on the PCB to facilitate the design of enclosures. The Connector now sticks out from the PCB board edge, allowing a 3D printed enclosure or similar to allow flush access to t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
    [micromirror-board-controller.kicad_pcb]
2024-04-25 Add PCB evaluation results
    Confirm the testing and verification of the PCB. It is now safe to order the PCB and reproduce the project.
2024-04-25 Fix silkscreen error
    Extra GPIO pins had GND and 3.3V labels flipped. Corrected.
    [micromirror-board-controller.kicad_pcb]
2024-04-26 Add simple printable enclosure
    Simple enclosure helps keep the cables from getting strained when the projector is moved. Needs a lid, but this is just a quick and simple design.
    [enclosure-bottom.step, enclosure-top.step, enclosure.FCStd]
